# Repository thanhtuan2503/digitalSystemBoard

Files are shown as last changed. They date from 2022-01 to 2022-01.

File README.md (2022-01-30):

# INTRODUCTION TO TICKIT VER1.0 - DIGITAL SYSTEM KIT
Item: Digital System KIT

Date: Jan 10th, 2022

Delivered to: HCMUT CE-LAB

Designed in Vietnam

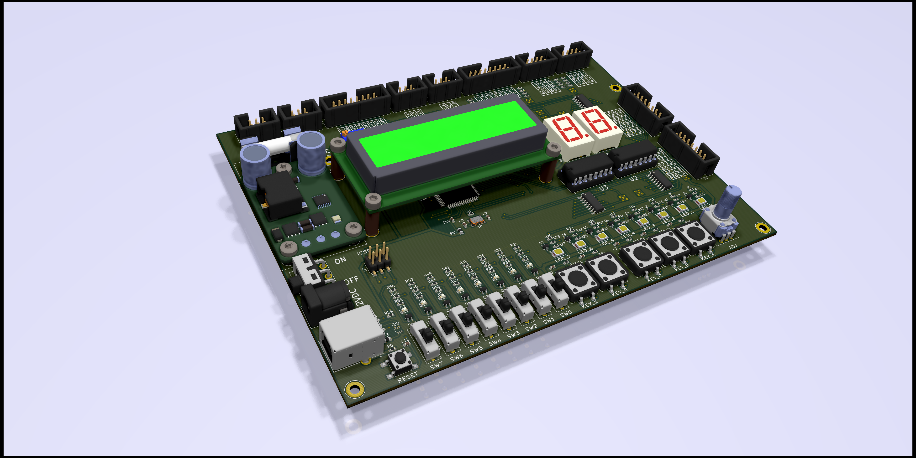
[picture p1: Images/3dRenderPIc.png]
3D Render Board with KiCad

<p align="center">
    3D Render Board with KiCad.
</p>

## TICKIT include all below function block: 
- PWM Generator with  microcontroller ATMEGA64A.
- Display LCD with 16x2 characters.
-  5 Buttons 12x12 mm.
- 8 Switchs 21.1x5.5 mm.
- 8 Display LEDs size 3.5x2.8 mm.
- 2 7- segment LEDs.

Product Introduction in CSE Facebook page :[ KIT thí nghiệm môn học Hệ thống số do thầy và trò Khoa KH&KTMT thiết kế và phát triển](https://www.facebook.com/2180160732207910/posts/3021461968077778/).

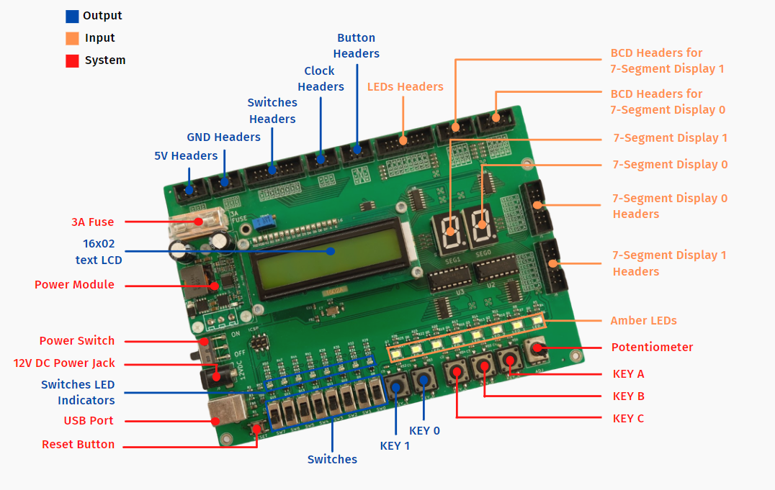
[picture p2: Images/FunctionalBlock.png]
Some functional blocks in TICKIT

<p align="center">
    Some functional blocks in TICKIT.
</p>

##  What's in the Box?
1. TickLab-DSKiT 1.0 Board.

2. TickLab-DSKiT 1.0 Quick Start Guide.

3. Small Screwdriver.

## Documentations and Resources
Available for free access at https://ticklab.vn/dskit

## Getting ready
1. Make sure a 3A fuse tube is properly inserted.

2. Connect the power adapter to the power jack on the board, then turn on the power switch.

3. As soon as the board is powered up, the self-test must be started. The amber LED and 7-segment display will blink at 2Hz during the self-test so you can detect early if any LEDs are dead.

## Fatal Cautions

1. DO NOT connect any outputs to another output. Connecting an output to another one may cause circuit damage, a fire, or an explosion despite a 3A fuse installed.

2. Keep liquid or no-used metal things far away from the board to avoid making a short circuit.

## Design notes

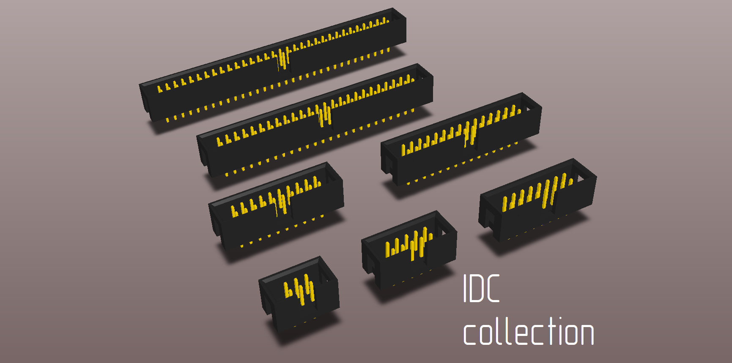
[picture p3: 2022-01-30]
digitalSystemBoard/3dSymbol/IDC_prev.png

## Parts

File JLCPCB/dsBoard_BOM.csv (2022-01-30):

Comment | Designator | Footprint | LCSC
0.1uF | C0,C1,C2,C3,C4,C5,C6,C9,C10,C12,C14 | Capacitor_SMD:C_0603_1608Metric | C14663
22pF | C7,C8,C11,C13 | Capacitor_SMD:C_0603_1608Metric | C1653
LED | D0,D1,D2,D3,D4,D5,D6,D7 | LED_SMD:LED_0603_1608Metric | C72043
WC1602A | DS1 | digitalSystemBoard:WC1602A
3A | F0 | digitalSystemBoard:Fuse
80Ohm | FB1,FB3,FB4,FB5 | digitalSystemBoard:FerriteBead | C141982
MountingHole | H0,H1,H2,H3 | digitalSystemBoard:Mountinghole_M3
Barrel_Jack | J0 | Connector_BarrelJack:BarrelJack_Horizontal
USB-B | J1 | digitalSystemBoard:SAMTEC_USB-B-S-X-X-TH-TR
Conn_02x04_Odd_Even | J2,J3 | Connector_IDC:IDC-Header_2x04_P2.54mm_Vertical
Conn_02x07_Odd_Even | J5,J6 | Connector_IDC:IDC-Header_2x07_P2.54mm_Vertical
Conn_02x08_Odd_Even | J4,J7 | Connector_IDC:IDC-Header_2x08_P2.54mm_Vertical
Conn_02x03_Odd_Even | J8,J9,J10,J11 | Connector_IDC:IDC-Header_2x03_P2.54mm_Vertical
ButtonFirst | KEY0,KEY1,KEY2,KEY3,KEY4 | digitalSystemBoard:Button
LED | LED0,LED1,LED2,LED3,LED4,LED5,LED6,LED7 | digitalSystemBoard:LED_3528 | C210324
Power_Module | PM0 | digitalSystemBoard:Power_Module
BC847 | Q0,Q1,Q2,Q3,Q4,Q5,Q6,Q7,Q8,Q9,Q10,Q11,Q12,Q13,Q14,Q15 | digitalSystemBoard:SO65P210X100-3N | C8659
1M | R1 | Resistor_SMD:R_0603_1608Metric | C22935
22 | R0,R2,R3 | Resistor_SMD:R_0603_1608Metric | C23345
27k | R28,R31,R34,R37,R40,R43,R46,R49 | Resistor_SMD:R_0603_1608Metric | C22967
4.7k | R29,R32,R35,R38,R41,R44,R47,R50 | Resistor_SMD:R_0603_1608Metric | C23162
1.8k | R30,R33,R36,R39,R42,R45,R48,R51 | Resistor_SMD:R_0603_1608Metric | C4177
15k | R4,R7,R10,R13,R16,R19,R22,R25 | Resistor_SMD:R_0603_1608Metric | C22809
10k | R52,R53,R54,R55,R56,R59,R82,R83,R84,R85,R86,R87,R88,R89 | Resistor_SMD:R_0603_1608Metric | C25804
220 | R58 | Resistor_SMD:R_0603_1608Metric | C22962
2.49k | R5,R6,R8,R9,R11,R12,R14,R15,R17,R18,R20,R21,R23,R24,R26,R27 | Resistor_SMD:R_0603_1608Metric | C108190
330 | R60,R61,R62,R63,R64,R65,R66,R67,R68,R69,R70,R71,R72,R73 | Resistor_SMD:R_0603_1608Metric | C23138
47k | R74,R75,R76,R77,R78,R79,R80,R81 | Resistor_SMD:R_0603_1608Metric | C25819
SW_SPDT | SW0 | digitalSystemBoard:SS-12D11
IO_Switch | SW1,SW2,SW3,SW4,SW5,SW6,SW7,SW8 | digitalSystemBoard:SS-12F44G5
ButtonFirst | SW9 | digitalSystemBoard:Button_CLOCK
SMF05C.TCT | TD0 | digitalSystemBoard:SC70-6 | C558425
Potentiometer | TRIM0 | digitalSystemBoard:TRIM_3296W-1-501
KCSA02-105 | U0,U1 | Display_7Segment:7SegmentLED_LTS6760_LTS6780
74HC595 | U9,U11 | Package_SO:SOIC-16_3.9x9.9mm_P1.27mm | C5947
ATmega64A-AU | U12 | Package_QFP:TQFP-64_14x14mm_P0.8mm | C9435
74LS47 | U2,U3 | digitalSystemBoard:DIP_16_PIN_SOCKET
74HC04 | U4 | Package_SO:SOIC-14_3.9x8.7mm_P1.27mm | C5590
Potentiometer | U5 | digitalSystemBoard:RV09S
CH340G | U6 | Package_SO:SOIC-16_3.9x9.9mm_P1.27mm | C14267
ICSP | U7 | Connector_PinHeader_2.54mm:PinHeader_2x03_P2.54mm_Vertical_SMD
74HC165 | U8,U10 | Package_SO:SOIC-16_3.9x9.9mm_P1.27mm | C5613
16MHz | Y0 | Crystal:Crystal_SMD_Abracon_ABM3B-4Pin_5.0x3.2mm | C112586
12MHz | Y1 | Crystal:Crystal_SMD_Abracon_ABM8G-4Pin_3.2x2.5mm | C258939

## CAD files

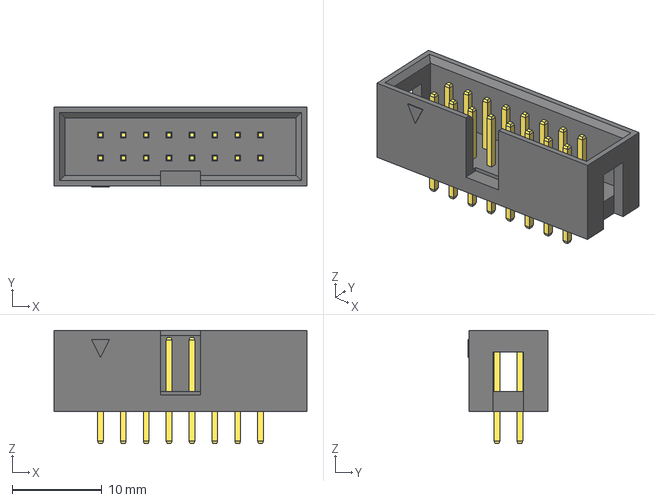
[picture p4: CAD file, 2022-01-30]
digitalSystemBoard/3dSymbol/DS1013 (IDC CONNFLY)/DS1013-16S (IDC-16MS CONNFLY).stp
28.1 x 8.90 x 12.6 mm

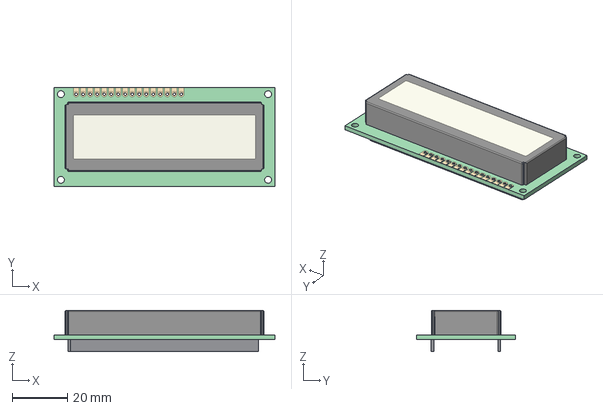
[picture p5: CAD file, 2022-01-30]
digitalSystemBoard/3dSymbol/WC1602A.step
80.0 x 36.0 x 15.0 mm

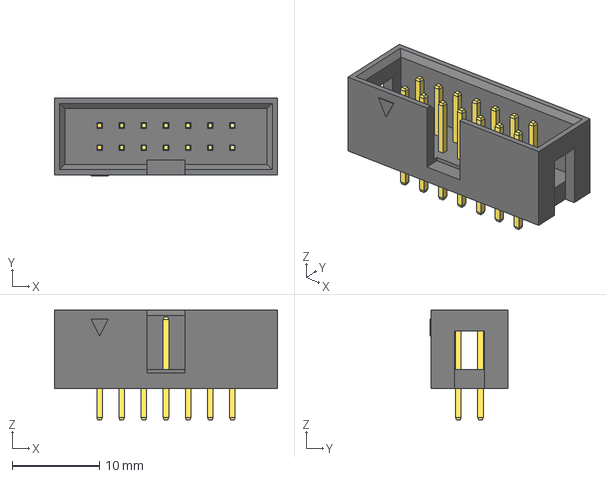
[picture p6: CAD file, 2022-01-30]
digitalSystemBoard/3dSymbol/DS1013 (IDC CONNFLY)/DS1013-14S (IDC-14MS CONNFLY).stp
25.6 x 8.90 x 12.6 mm

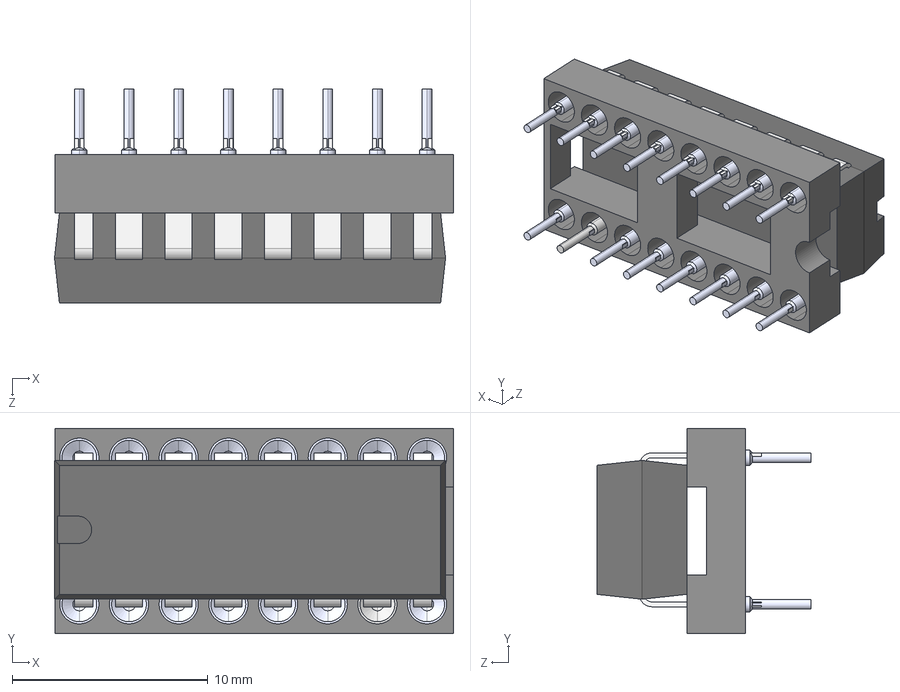
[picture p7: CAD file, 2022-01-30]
digitalSystemBoard/3dSymbol/User-Library-DIP-16-_-socket-214_V3.step
20.4 x 10.5 x 10.9 mm
DIP16 socket62.STEP.STEP
DIP16 socket60.STEP.STEP
DIP16 socket68.STEP.STEP
DIP16 socket53.STEP.STEP
DIP16 socket54.STEP.STEP
DIP16 socket67.STEP.STEP
DIP16 socket57.STEP.STEP
DIP16 socket66.STEP.STEP
DIP16 socket52.STEP.STEP
DIP16 socket59.STEP.STEP
DIP 16 IC4.STEP.STEP
DIP16 socket55.STEP.STEP
DIP16 socket58.STEP.STEP
DIP16 socket63.STEP.STEP
DIP16 socket61.STEP.STEP
DIP16 socket56.STEP.STEP
DIP16 socket65.STEP.STEP
DIP16 socket64.STEP.STEP

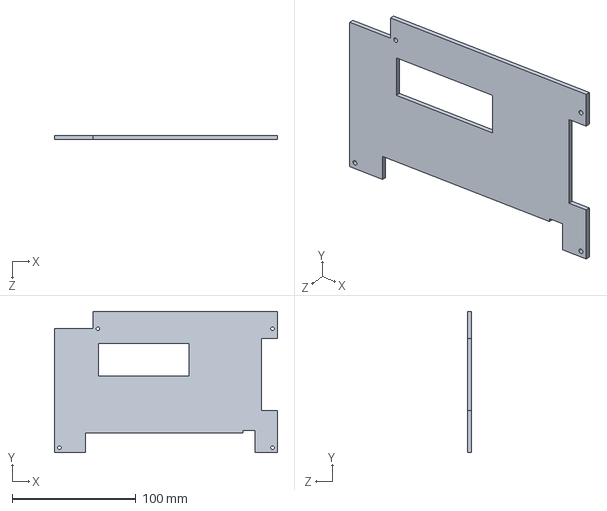
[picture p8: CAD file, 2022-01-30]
PlasticCover/Part1.sldprt
180.0 x 114.0 x 3.00 mm

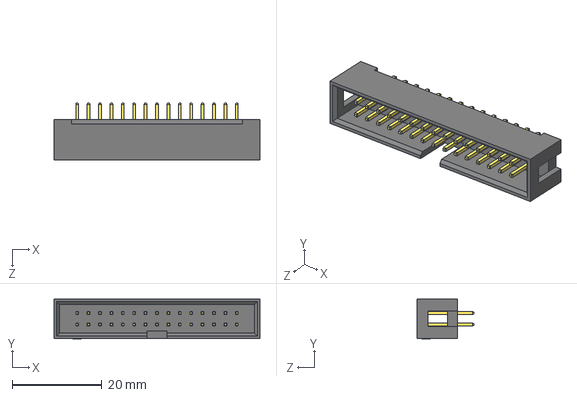
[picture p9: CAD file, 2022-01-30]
digitalSystemBoard/3dSymbol/DS1013 (IDC CONNFLY)/DS1013-30S (IDC-30MS CONNFLY).step
45.9 x 8.90 x 12.6 mm

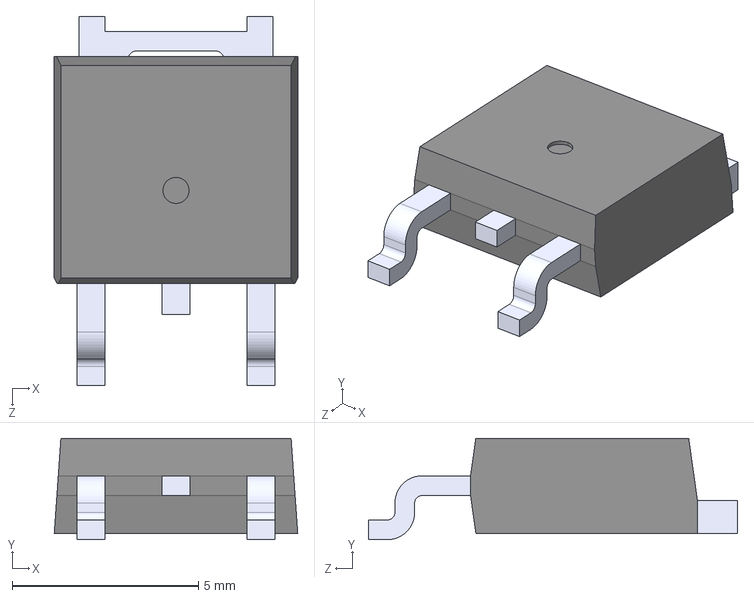
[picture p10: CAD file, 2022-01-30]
digitalSystemBoard/3dSymbol/LM317AMDT.STEP
6.54 x 2.72 x 9.91 mm

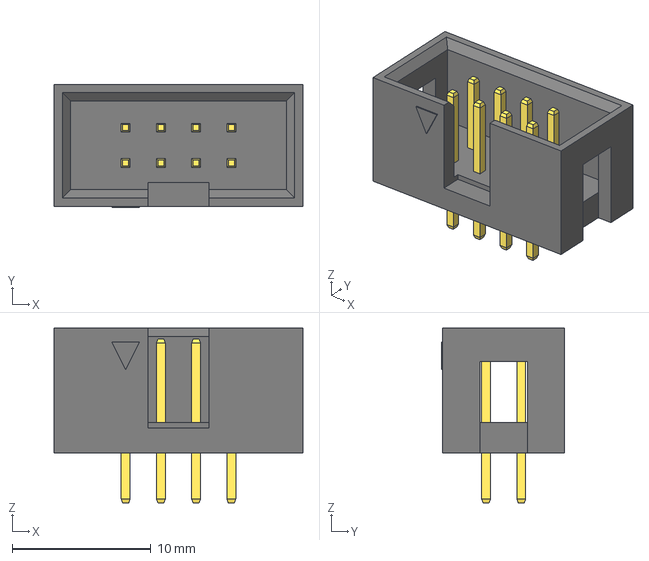
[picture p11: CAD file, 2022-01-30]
digitalSystemBoard/3dSymbol/DS1013 (IDC CONNFLY)/DS1013-8S (IDC-8MS CONNFLY).stp
18.0 x 8.90 x 12.6 mm

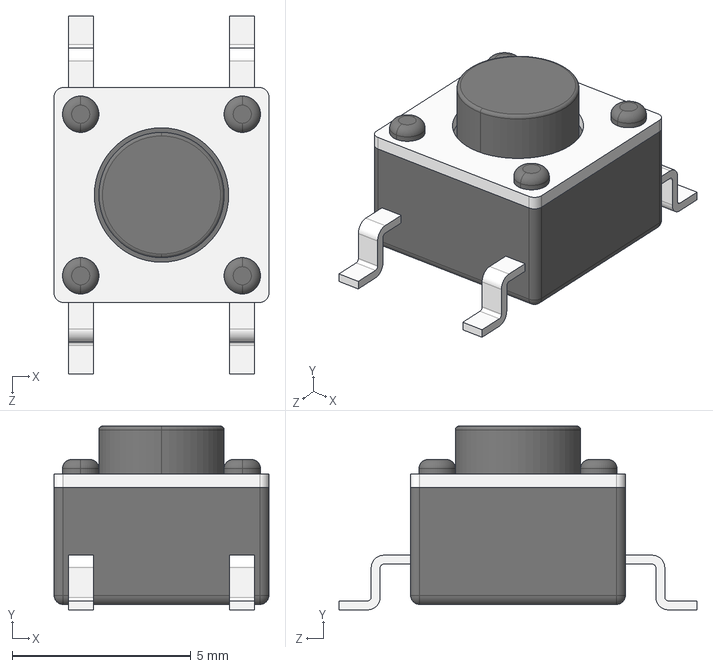
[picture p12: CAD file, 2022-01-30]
digitalSystemBoard/3dSymbol/FSM4JSMA_V2.step
6.00 x 5.13 x 10.0 mm

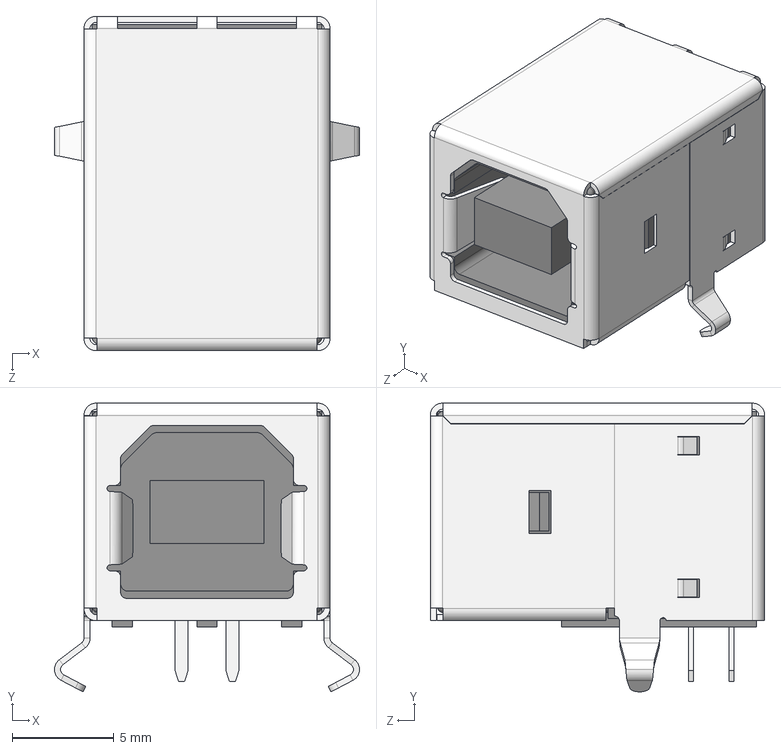
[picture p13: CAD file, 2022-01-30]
digitalSystemBoard/3dSymbol/CUI_DEVICES_UJ2-BH-1-TH.step
15.0 x 14.2 x 16.5 mm

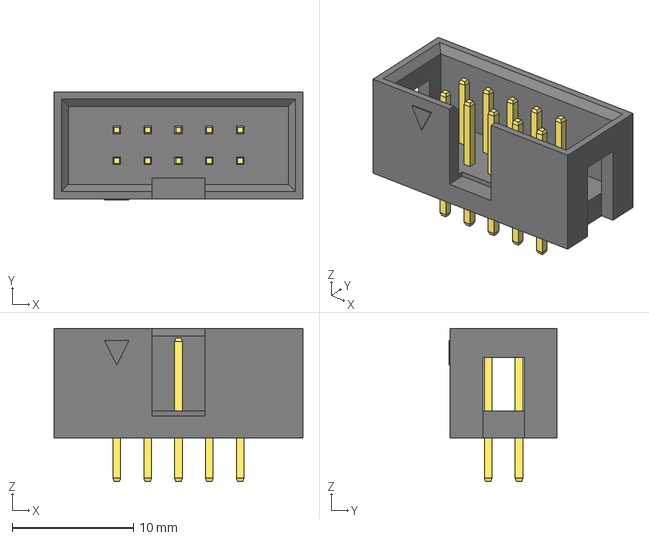
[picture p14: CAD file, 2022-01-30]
digitalSystemBoard/3dSymbol/DS1013 (IDC CONNFLY)/DS1013-10S (IDC-10MS CONNFLY).stp
20.5 x 8.90 x 12.6 mm

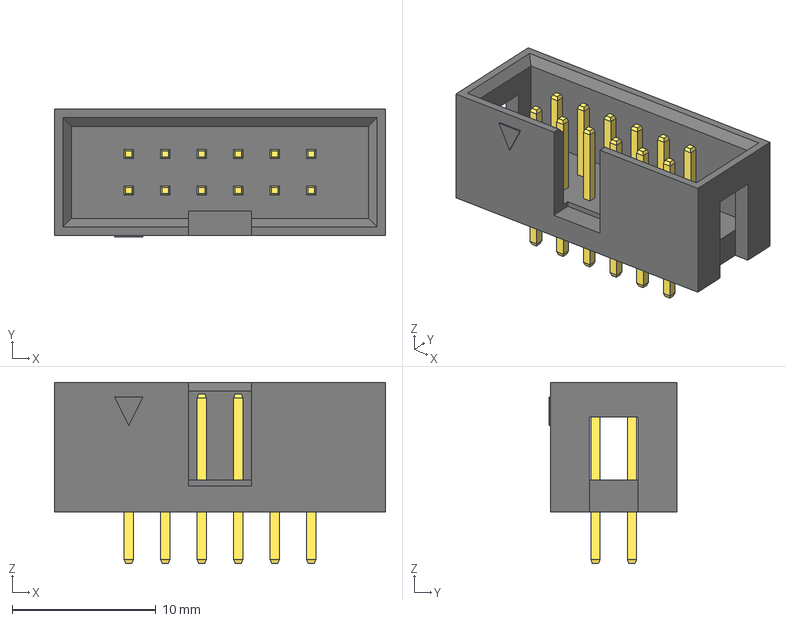
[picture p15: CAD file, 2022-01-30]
digitalSystemBoard/3dSymbol/DS1013 (IDC CONNFLY)/DS1013-12S (IDC-12MS CONNFLY).stp
23.0 x 8.90 x 12.6 mm

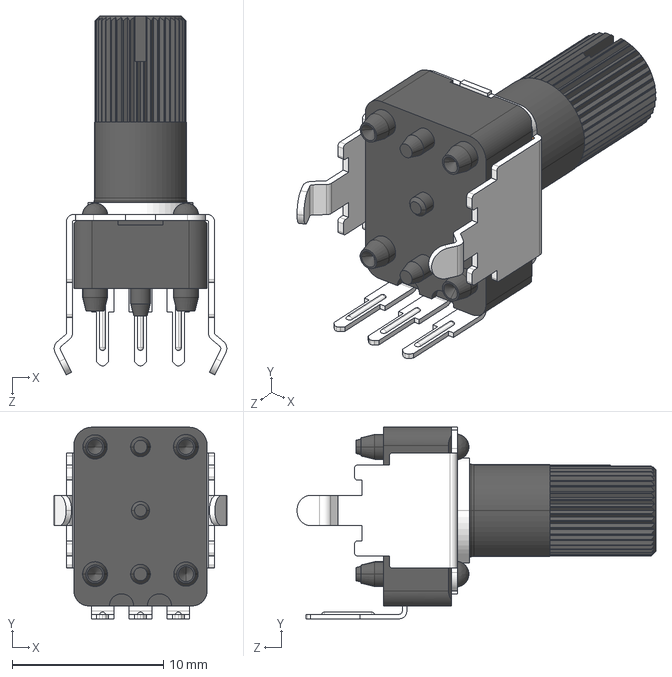
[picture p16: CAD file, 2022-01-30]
digitalSystemBoard/3dSymbol/User-Library-RK09K1130-20-1.step
11.4 x 12.7 x 23.7 mm

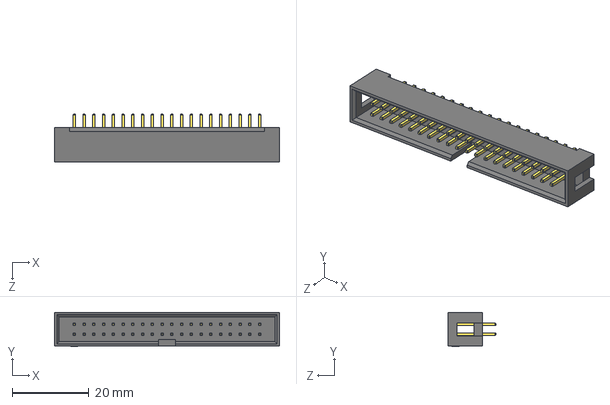
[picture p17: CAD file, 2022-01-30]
digitalSystemBoard/3dSymbol/DS1013 (IDC CONNFLY)/DS1013-40S (IDC-40MS CONNFLY).step
58.6 x 8.90 x 12.6 mm

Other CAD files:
PlasticCover/mica_ver2.0.DWG
digitalSystemBoard/3dSymbol/Fuse.step
digitalSystemBoard/3dSymbol/DS1013 (IDC CONNFLY)/DS1013-50S (IDC-50MS CONNFLY).step
digitalSystemBoard/3dSymbol/Fuse_V2.step
PlasticCover/Part1.SLDDRW
digitalSystemBoard/3dSymbol/2N7002--3DModel-STEP-56544.STEP
digitalSystemBoard/3dSymbol/3296W-1-501.STEP
digitalSystemBoard/3dSymbol/3528 SMD LED.stp
digitalSystemBoard/3dSymbol/BC847BW,115.STEP
digitalSystemBoard/3dSymbol/BC847BW,115Old.STEP
digitalSystemBoard/3dSymbol/DIP_16_PIN_SOCKET.stp
digitalSystemBoard/3dSymbol/DS1013 (IDC CONNFLY)/DS1013-20S (IDC-20MS CONNFLY).stp
digitalSystemBoard/3dSymbol/DS1013 (IDC CONNFLY)/DS1013-26S (IDC-26MS CONNFLY).stp
digitalSystemBoard/3dSymbol/DS1013 (IDC CONNFLY)/DS1013-34S (IDC-34MS CONNFLY).step
digitalSystemBoard/3dSymbol/DS1013 (IDC CONNFLY)/DS1013-60S (IDC-60MS CONNFLY).step
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

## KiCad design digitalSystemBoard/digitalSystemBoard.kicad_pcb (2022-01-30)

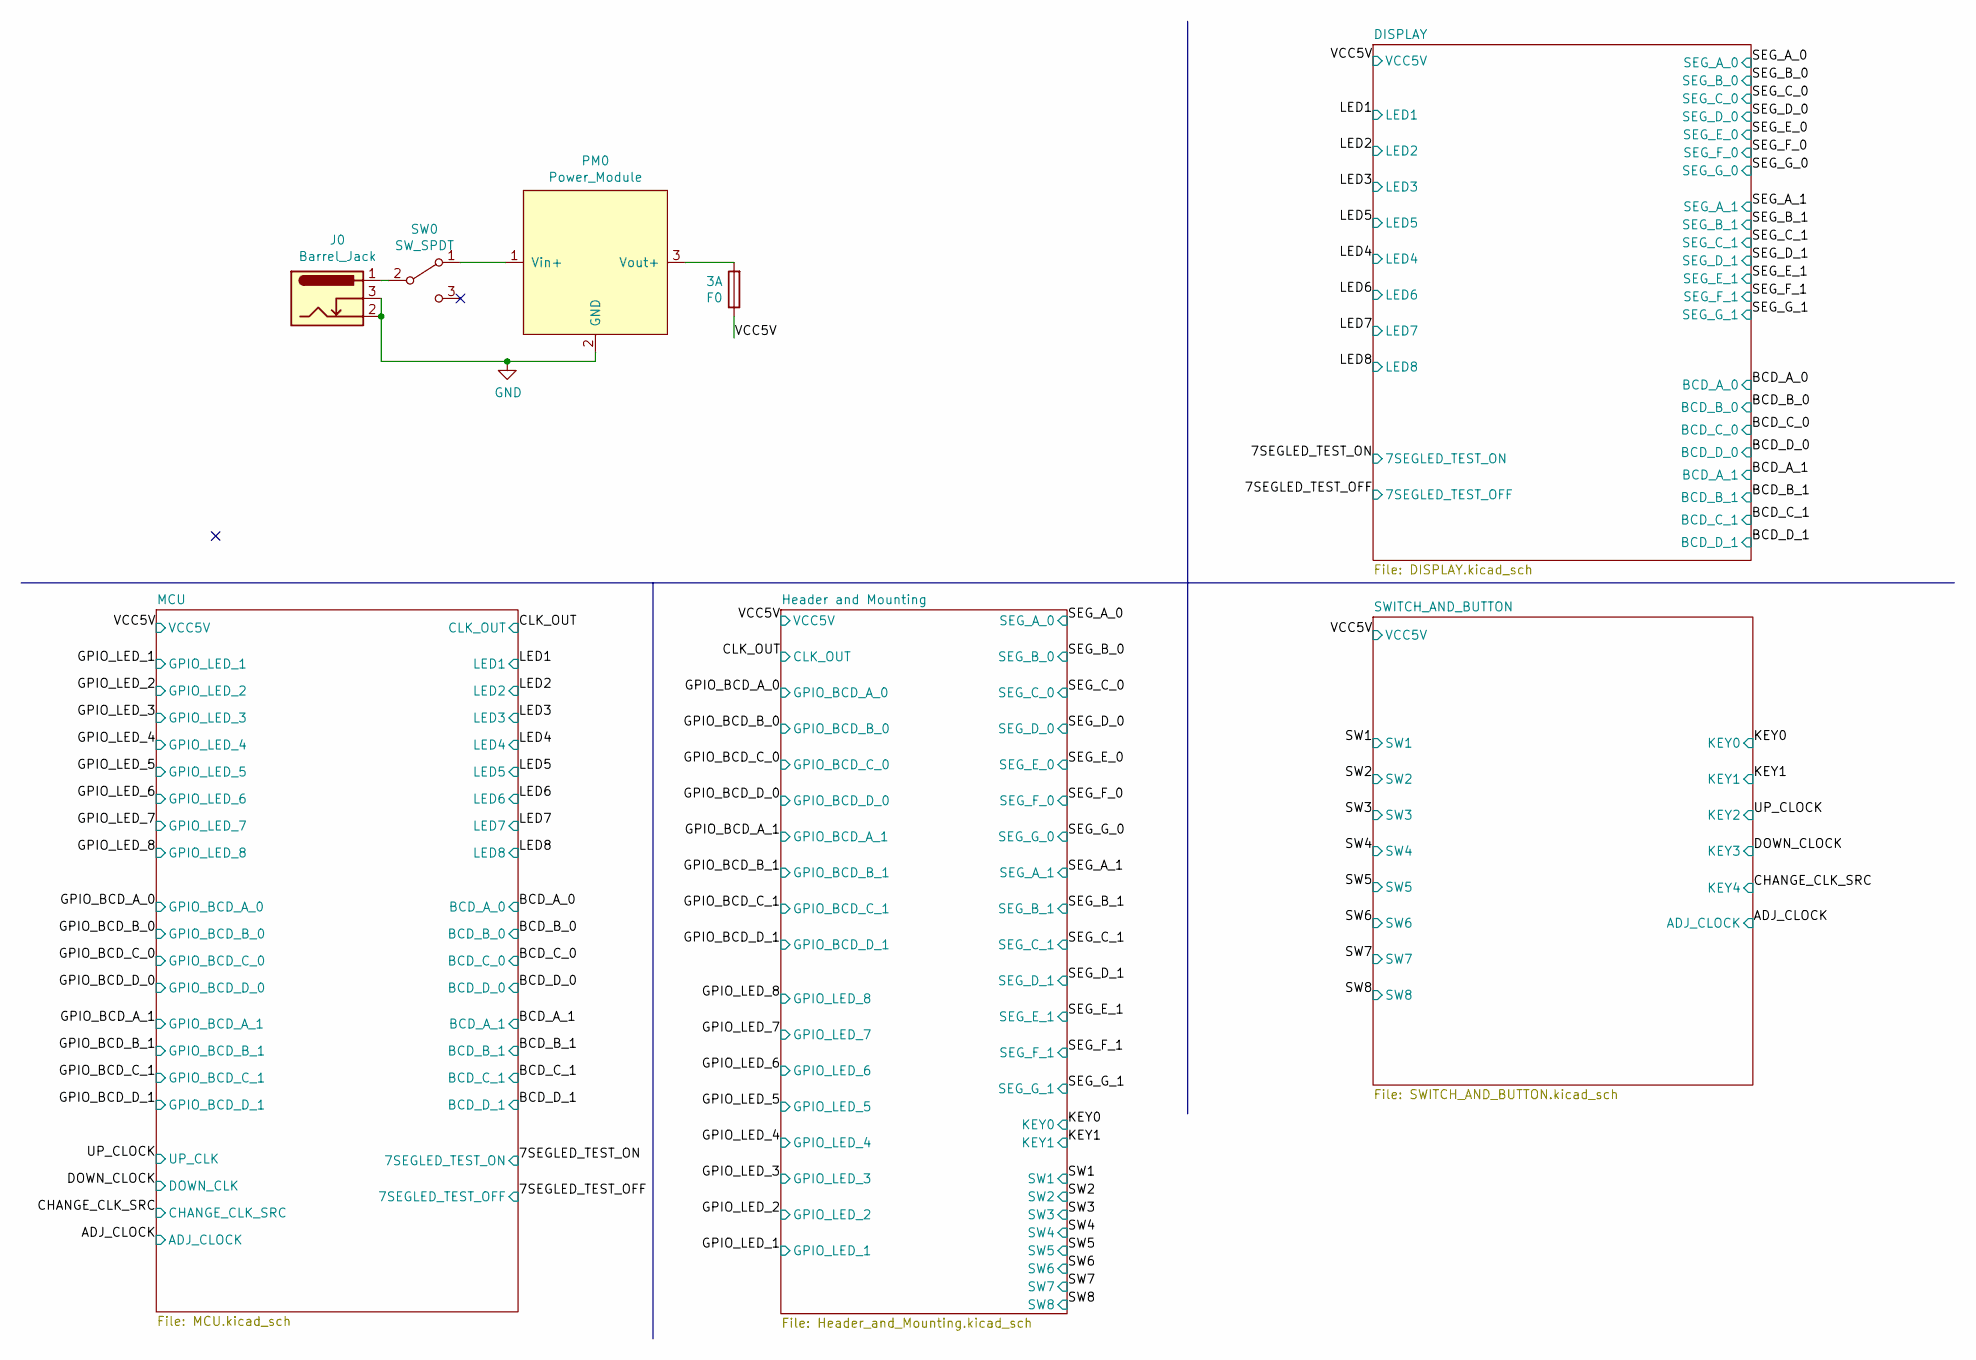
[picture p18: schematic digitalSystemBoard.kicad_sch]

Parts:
F0: 3A; Fuse
J0: Barrel_Jack; BarrelJack_Horizontal
PM0: Power_Module
SW0: SW_SPDT; SS-12D11

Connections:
/VCC5V: F0.1; also elsewhere on the board
GND: J0.2, J0.3, PM0.2 (GND); also elsewhere on the board
unnamed: F0.2, PM0.3 (Vout+)
unnamed: J0.1, SW0.2 (B)
unnamed: PM0.1 (Vin+), SW0.1 (A)

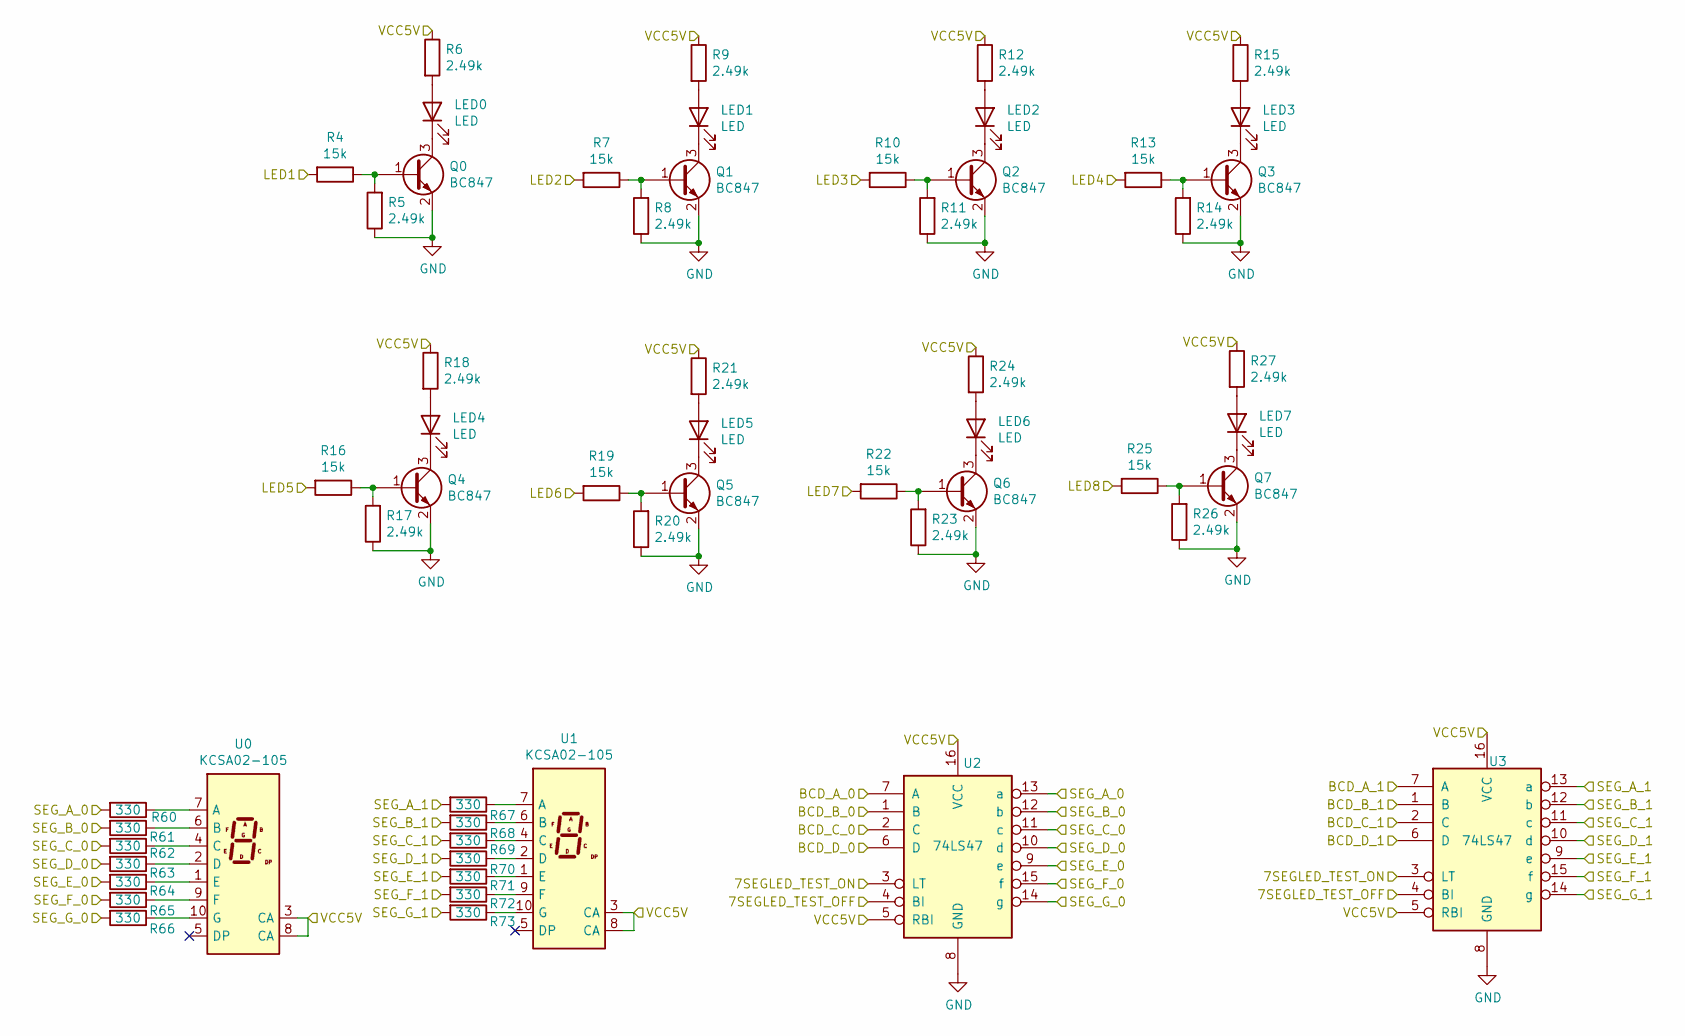
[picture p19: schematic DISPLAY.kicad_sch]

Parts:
LED0, LED1, LED2, LED3, LED4, LED5, LED6, LED7: LED; LED_3528; LCSC C73545
Q0, Q1, Q2, Q3, Q4, Q5, Q6, Q7: BC847; SO65P210X100-3N; LCSC C8659
R4, R7, R10, R13, R16, R19, R22, R25: 15k; R_0603_1608Metric; LCSC C100780
R5, R6, R8, R9, R11, R12, R14, R15, R17, R18, R20, R21, R23, R24, R26, R27: 2.49k; R_0603_1608Metric; LCSC C22908
R60, R61, R62, R63, R64, R65, R66, R67, R68, R69, R70, R71, R72, R73: 330; R_0603_1608Metric; LCSC C23138
U0, U1: KCSA02-105; 7SegmentLED_LTS6760_LTS6780
U2, U3: 74LS47; DIP_16_PIN_SOCKET

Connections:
/7SEGLED_TEST_OFF: U2.4 (BI), U3.4 (BI); also elsewhere on the board
/7SEGLED_TEST_ON: U2.3 (LT), U3.3 (LT); also elsewhere on the board
/BCD_A_0: U2.7 (A); also elsewhere on the board
/BCD_A_1: U3.7 (A); also elsewhere on the board
/BCD_B_0: U2.1 (B); also elsewhere on the board
/BCD_B_1: U3.1 (B); also elsewhere on the board
/BCD_C_0: U2.2 (C); also elsewhere on the board
/BCD_C_1: U3.2 (C); also elsewhere on the board
/BCD_D_0: U2.6 (D); also elsewhere on the board
/BCD_D_1: U3.6 (D); also elsewhere on the board
/LED1: R4.2; also elsewhere on the board
/LED2: R7.2; also elsewhere on the board
/LED3: R10.2; also elsewhere on the board
/LED4: R13.2; also elsewhere on the board
/LED5: R16.2; also elsewhere on the board
/LED6: R19.2; also elsewhere on the board
/LED7: R22.2; also elsewhere on the board
/LED8: R25.2; also elsewhere on the board
/SEG_A_0: R60.2, U2.13 (a); also elsewhere on the board
/SEG_A_1: R67.2, U3.13 (a); also elsewhere on the board
/SEG_B_0: R61.2, U2.12 (b); also elsewhere on the board
/SEG_B_1: R68.2, U3.12 (b); also elsewhere on the board
/SEG_C_0: R62.2, U2.11 (c); also elsewhere on the board
/SEG_C_1: R69.2, U3.11 (c); also elsewhere on the board
/SEG_D_0: R63.2, U2.10 (d); also elsewhere on the board
/SEG_D_1: R70.2, U3.10 (d); also elsewhere on the board
/SEG_E_0: R64.2, U2.9 (e); also elsewhere on the board
/SEG_E_1: R71.2, U3.9 (e); also elsewhere on the board
/SEG_F_0: R65.2, U2.15 (f); also elsewhere on the board
/SEG_F_1: R72.2, U3.15 (f); also elsewhere on the board
/SEG_G_0: R66.2, U2.14 (g); also elsewhere on the board
/SEG_G_1: R73.2, U3.14 (g); also elsewhere on the board
/VCC5V: R6.1, R9.1, R12.1, R15.1, R18.1, R21.1, R24.1, R27.1, U0.3 (CA), U0.8 (CA), U1.3 (CA), U1.8 (CA), U2.5 (RBI), U2.16 (VCC), U3.5 (RBI), U3.16 (VCC); also elsewhere on the board
GND: Q0.2 (E), Q1.2 (E), Q2.2 (E), Q3.2 (E), Q4.2 (E), Q5.2 (E), Q6.2 (E), Q7.2 (E), R5.1, R8.1, R11.1, R14.1, R17.1, R20.1, R23.1, R26.1, U2.8 (GND), U3.8 (GND); also elsewhere on the board
unnamed: LED0.1 (K), Q0.3 (C)
unnamed: LED0.2 (A), R6.2
unnamed: LED1.1 (K), Q1.3 (C)
unnamed: LED1.2 (A), R9.2
unnamed: LED2.1 (K), Q2.3 (C)
unnamed: LED2.2 (A), R12.2
unnamed: LED3.1 (K), Q3.3 (C)
unnamed: LED3.2 (A), R15.2
unnamed: LED4.1 (K), Q4.3 (C)
unnamed: LED4.2 (A), R18.2
unnamed: LED5.1 (K), Q5.3 (C)
unnamed: LED5.2 (A), R21.2
unnamed: LED6.1 (K), Q6.3 (C)
unnamed: LED6.2 (A), R24.2
unnamed: LED7.1 (K), Q7.3 (C)
unnamed: LED7.2 (A), R27.2
unnamed: Q0.1 (B), R4.1, R5.2
unnamed: Q1.1 (B), R7.1, R8.2
unnamed: Q2.1 (B), R10.1, R11.2
unnamed: Q3.1 (B), R13.1, R14.2
unnamed: Q4.1 (B), R16.1, R17.2
unnamed: Q5.1 (B), R19.1, R20.2
unnamed: Q6.1 (B), R22.1, R23.2
unnamed: Q7.1 (B), R25.1, R26.2
unnamed: R60.1, U0.7 (A)
unnamed: R61.1, U0.6 (B)
unnamed: R62.1, U0.4 (C)
unnamed: R63.1, U0.2 (D)
unnamed: R64.1, U0.1 (E)
unnamed: R65.1, U0.9 (F)
unnamed: R66.1, U0.10 (G)
unnamed: R67.1, U1.7 (A)
unnamed: R68.1, U1.6 (B)
unnamed: R69.1, U1.4 (C)
unnamed: R70.1, U1.2 (D)
unnamed: R71.1, U1.1 (E)
unnamed: R72.1, U1.9 (F)
unnamed: R73.1, U1.10 (G)

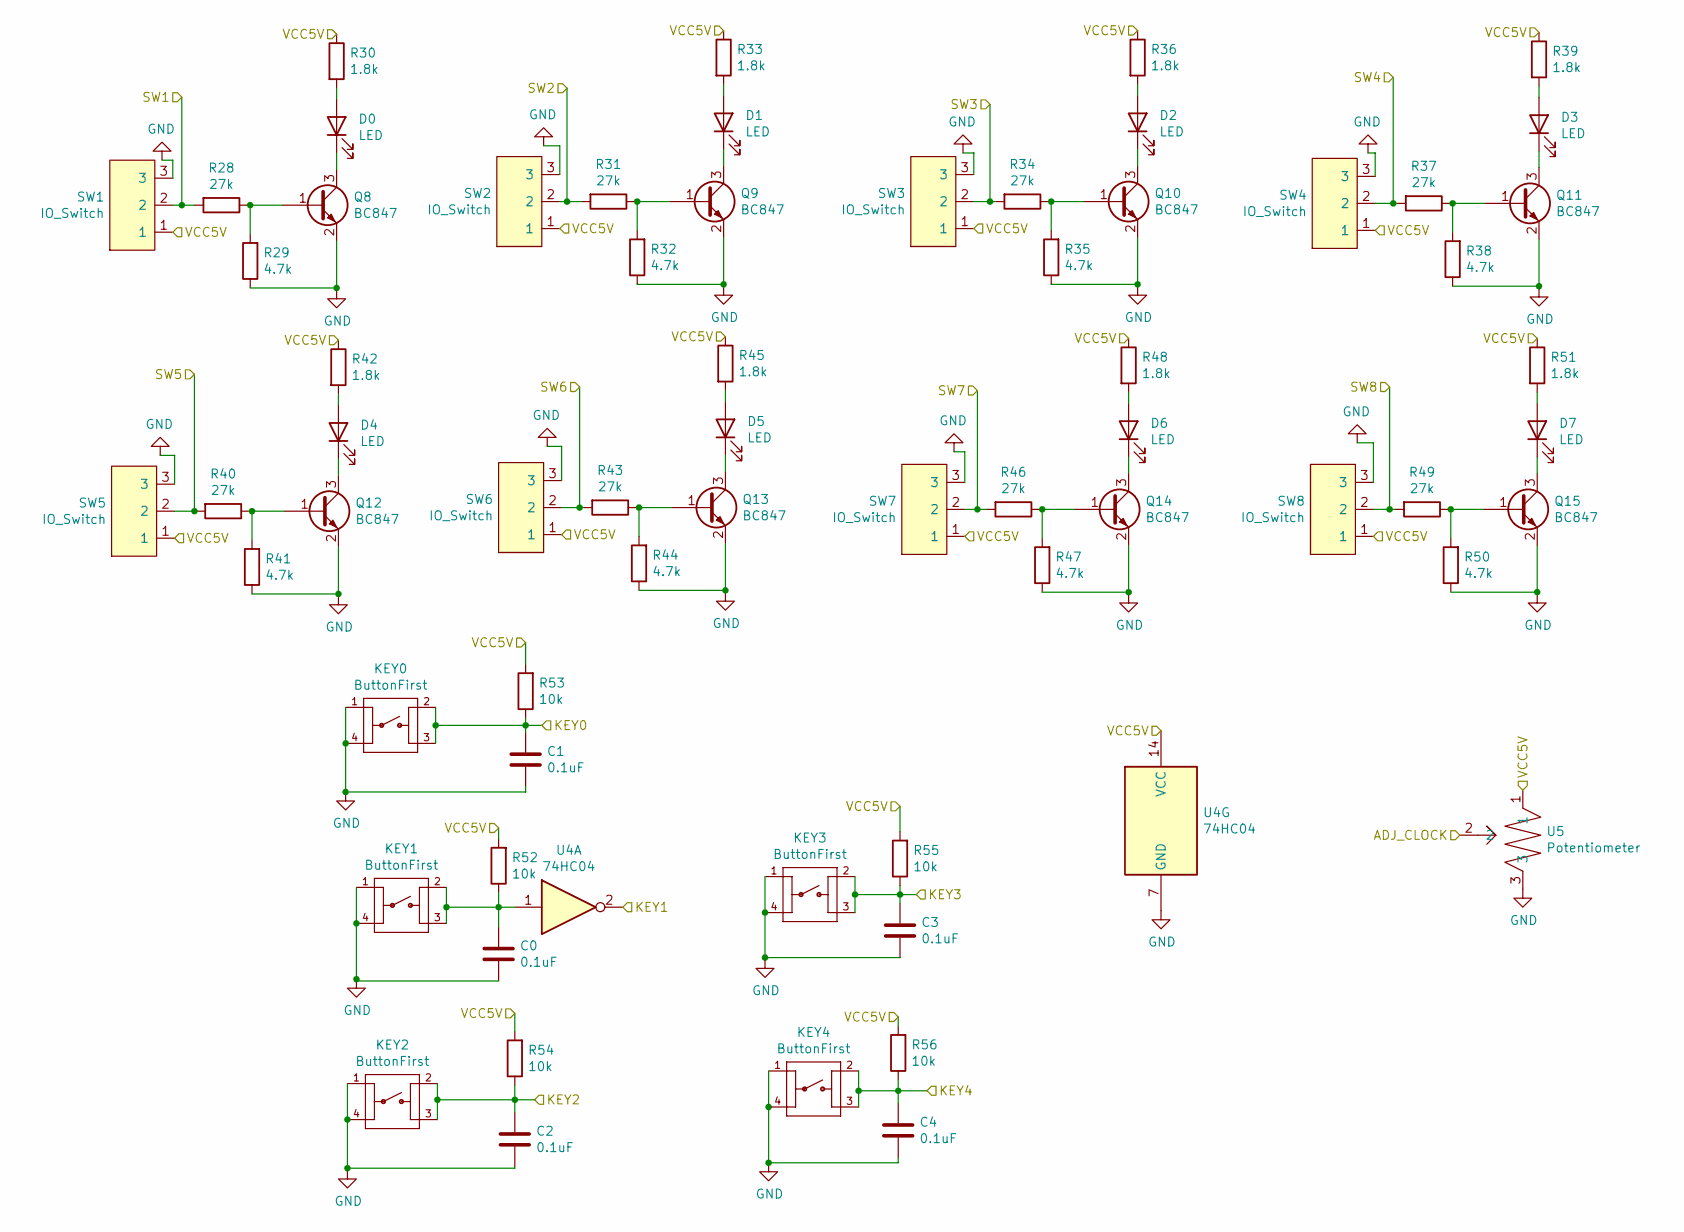
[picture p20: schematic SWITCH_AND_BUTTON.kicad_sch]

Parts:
C0, C1, C2, C3, C4: 0.1uF; C_0603_1608Metric; LCSC C14663
D0, D1, D2, D3, D4, D5, D6, D7: LED; LED_0603_1608Metric; LCSC C72043
KEY0, KEY1, KEY2, KEY3, KEY4: ButtonFirst; Button
Q8, Q9, Q10, Q11, Q12, Q13, Q14, Q15: BC847; SO65P210X100-3N; LCSC C8659
R28, R31, R34, R37, R40, R43, R46, R49: 27k; R_0603_1608Metric; LCSC C25589
R29, R32, R35, R38, R41, R44, R47, R50: 4.7k; R_0603_1608Metric; LCSC C23162
R30, R33, R36, R39, R42, R45, R48, R51: 1.8k; R_0603_1608Metric; LCSC C103360
R52, R53, R54, R55, R56: 10k; R_0603_1608Metric; LCSC C98220
SW1, SW2, SW3, SW4, SW5, SW6, SW7, SW8: IO_Switch; SS-12F44G5
U4: 74HC04; SOIC-14_3.9x8.7mm_P1.27mm; LCSC C5590
U5: Potentiometer; RV09S

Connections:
/ADJ_CLOCK: U5.2; also elsewhere on the board
/CHANGE_CLK_SRC: C4.1, KEY4.2 (e~), KEY4.3, R56.1; also elsewhere on the board
/DOWN_CLOCK: C3.2, KEY3.2 (e~), KEY3.3, R55.1; also elsewhere on the board
/KEY0: C1.1, KEY0.2 (e~), KEY0.3, R53.1; also elsewhere on the board
/KEY1: U4.2; also elsewhere on the board
/SW1: R28.2, SW1.2; also elsewhere on the board
/SW2: R31.2, SW2.2; also elsewhere on the board
/SW3: R34.2, SW3.2; also elsewhere on the board
/SW4: R37.2, SW4.2; also elsewhere on the board
/SW5: R40.2, SW5.2; also elsewhere on the board
/SW6: R43.2, SW6.2; also elsewhere on the board
/SW7: R46.2, SW7.2; also elsewhere on the board
/SW8: R49.2, SW8.2; also elsewhere on the board
/UP_CLOCK: C2.1, KEY2.2 (e~), KEY2.3, R54.1; also elsewhere on the board
/VCC5V: R30.1, R33.1, R36.1, R39.1, R42.1, R45.1, R48.1, R51.1, R52.2, R53.2, R54.2, R55.2, R56.2, SW1.1, SW2.1, SW3.1, SW4.1, SW5.1, SW6.1, SW7.1, SW8.1, U4.14 (VCC), U5.1; also elsewhere on the board
GND: C0.2, C1.2, C2.2, C3.1, C4.2, KEY0.1, KEY0.4, KEY1.1, KEY1.4, KEY2.1, KEY2.4, KEY3.1, KEY3.4, KEY4.1, KEY4.4, Q8.2 (E), Q9.2 (E), Q10.2 (E), Q11.2 (E), Q12.2 (E), Q13.2 (E), Q14.2 (E), Q15.2 (E), R29.1, R32.1, R35.1, R38.1, R41.1, R44.1, R47.1, R50.1, SW1.3, SW2.3, SW3.3, SW4.3, SW5.3, SW6.3, SW7.3, SW8.3, U4.7 (GND), U5.3; also elsewhere on the board
unnamed: C0.1, KEY1.2 (e~), KEY1.3, R52.1, U4.1
unnamed: D0.1 (K), Q8.3 (C)
unnamed: D0.2 (A), R30.2
unnamed: D1.1 (K), Q9.3 (C)
unnamed: D1.2 (A), R33.2
unnamed: D2.1 (K), Q10.3 (C)
unnamed: D2.2 (A), R36.2
unnamed: D3.1 (K), Q11.3 (C)
unnamed: D3.2 (A), R39.2
unnamed: D4.1 (K), Q12.3 (C)
unnamed: D4.2 (A), R42.2
unnamed: D5.1 (K), Q13.3 (C)
unnamed: D5.2 (A), R45.2
unnamed: D6.1 (K), Q14.3 (C)
unnamed: D6.2 (A), R48.2
unnamed: D7.1 (K), Q15.3 (C)
unnamed: D7.2 (A), R51.2
unnamed: Q8.1 (B), R28.1, R29.2
unnamed: Q9.1 (B), R31.1, R32.2
unnamed: Q10.1 (B), R34.1, R35.2
unnamed: Q11.1 (B), R37.1, R38.2
unnamed: Q12.1 (B), R40.1, R41.2
unnamed: Q13.1 (B), R43.1, R44.2
unnamed: Q14.1 (B), R46.1, R47.2
unnamed: Q15.1 (B), R49.1, R50.2

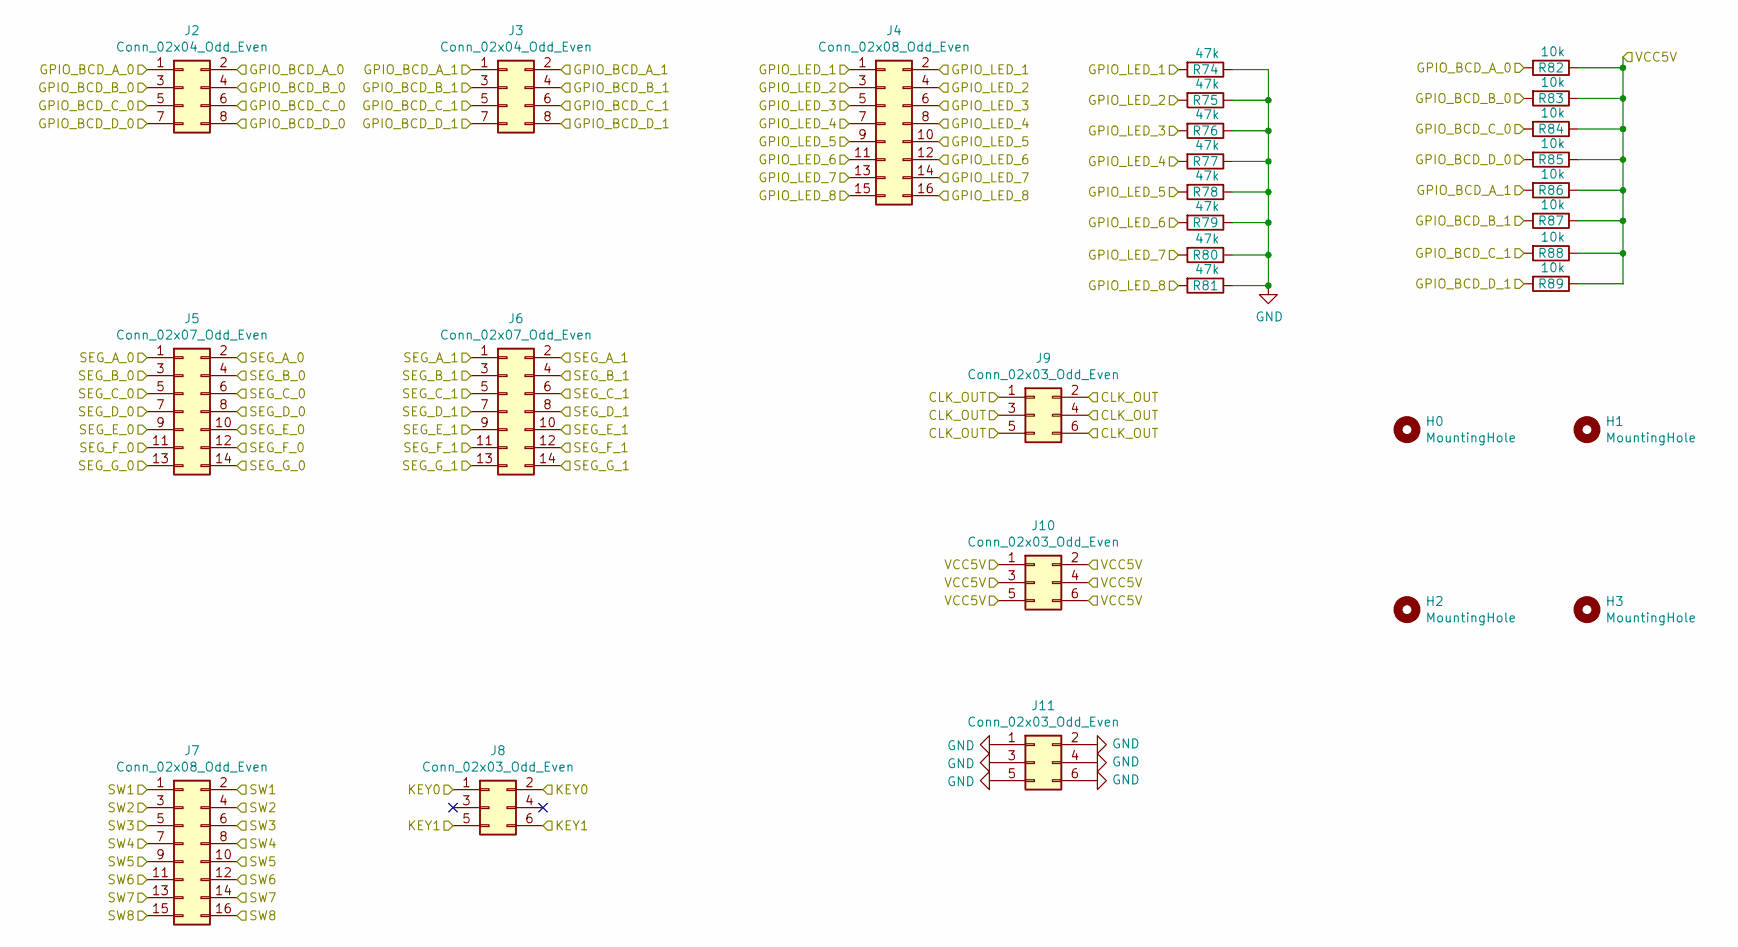
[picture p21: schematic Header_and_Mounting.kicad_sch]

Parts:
H0, H1, H2, H3: MountingHole; Mountinghole_M3
J2, J3: Conn_02x04_Odd_Even; IDC-Header_2x04_P2.54mm_Vertical
J4, J7: Conn_02x08_Odd_Even; IDC-Header_2x08_P2.54mm_Vertical
J5, J6: Conn_02x07_Odd_Even; IDC-Header_2x07_P2.54mm_Vertical
J8, J9, J10, J11: Conn_02x03_Odd_Even; IDC-Header_2x03_P2.54mm_Vertical
R74, R75, R76, R77, R78, R79, R80, R81: 47k; R_0603_1608Metric; LCSC C98220
R82, R83, R84, R85, R86, R87, R88, R89: 10k; R_0603_1608Metric; LCSC C98220

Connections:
/CLK_OUT: J9.1, J9.2, J9.3, J9.4, J9.5, J9.6; also elsewhere on the board
/GPIO_BCD_A_0: J2.1, J2.2, R82.2; also elsewhere on the board
/GPIO_BCD_A_1: J3.1, J3.2, R86.2; also elsewhere on the board
/GPIO_BCD_B_0: J2.3, J2.4, R83.2; also elsewhere on the board
/GPIO_BCD_B_1: J3.3, J3.4, R87.2; also elsewhere on the board
/GPIO_BCD_C_0: J2.5, J2.6, R84.2; also elsewhere on the board
/GPIO_BCD_C_1: J3.5, J3.6, R88.2; also elsewhere on the board
/GPIO_BCD_D_0: J2.7, J2.8, R85.2; also elsewhere on the board
/GPIO_BCD_D_1: J3.7, J3.8, R89.2; also elsewhere on the board
/GPIO_LED_1: J4.1, J4.2, R74.2; also elsewhere on the board
/GPIO_LED_2: J4.3, J4.4, R75.2; also elsewhere on the board
/GPIO_LED_3: J4.5, J4.6, R76.2; also elsewhere on the board
/GPIO_LED_4: J4.7, J4.8, R77.2; also elsewhere on the board
/GPIO_LED_5: J4.9, J4.10, R78.2; also elsewhere on the board
/GPIO_LED_6: J4.11, J4.12, R79.2; also elsewhere on the board
/GPIO_LED_7: J4.13, J4.14, R80.2; also elsewhere on the board
/GPIO_LED_8: J4.15, J4.16, R81.2; also elsewhere on the board
/KEY0: J8.1, J8.2; also elsewhere on the board
/KEY1: J8.5, J8.6; also elsewhere on the board
/SEG_A_0: J5.1, J5.2; also elsewhere on the board
/SEG_A_1: J6.1, J6.2; also elsewhere on the board
/SEG_B_0: J5.3, J5.4; also elsewhere on the board
/SEG_B_1: J6.3, J6.4; also elsewhere on the board
/SEG_C_0: J5.5, J5.6; also elsewhere on the board
/SEG_C_1: J6.5, J6.6; also elsewhere on the board
/SEG_D_0: J5.7, J5.8; also elsewhere on the board
/SEG_D_1: J6.7, J6.8; also elsewhere on the board
/SEG_E_0: J5.9, J5.10; also elsewhere on the board
/SEG_E_1: J6.9, J6.10; also elsewhere on the board
/SEG_F_0: J5.11, J5.12; also elsewhere on the board
/SEG_F_1: J6.11, J6.12; also elsewhere on the board
/SEG_G_0: J5.13, J5.14; also elsewhere on the board
/SEG_G_1: J6.13, J6.14; also elsewhere on the board
/SW1: J7.1, J7.2; also elsewhere on the board
/SW2: J7.3, J7.4; also elsewhere on the board
/SW3: J7.5, J7.6; also elsewhere on the board
/SW4: J7.7, J7.8; also elsewhere on the board
/SW5: J7.9, J7.10; also elsewhere on the board
/SW6: J7.11, J7.12; also elsewhere on the board
/SW7: J7.13, J7.14; also elsewhere on the board
/SW8: J7.15, J7.16; also elsewhere on the board
/VCC5V: J10.1, J10.2, J10.3, J10.4, J10.5, J10.6, R82.1, R83.1, R84.1, R85.1, R86.1, R87.1, R88.1, R89.1; also elsewhere on the board
GND: J11.1, J11.2, J11.3, J11.4, J11.5, J11.6, R74.1, R75.1, R76.1, R77.1, R78.1, R79.1, R80.1, R81.1; also elsewhere on the board

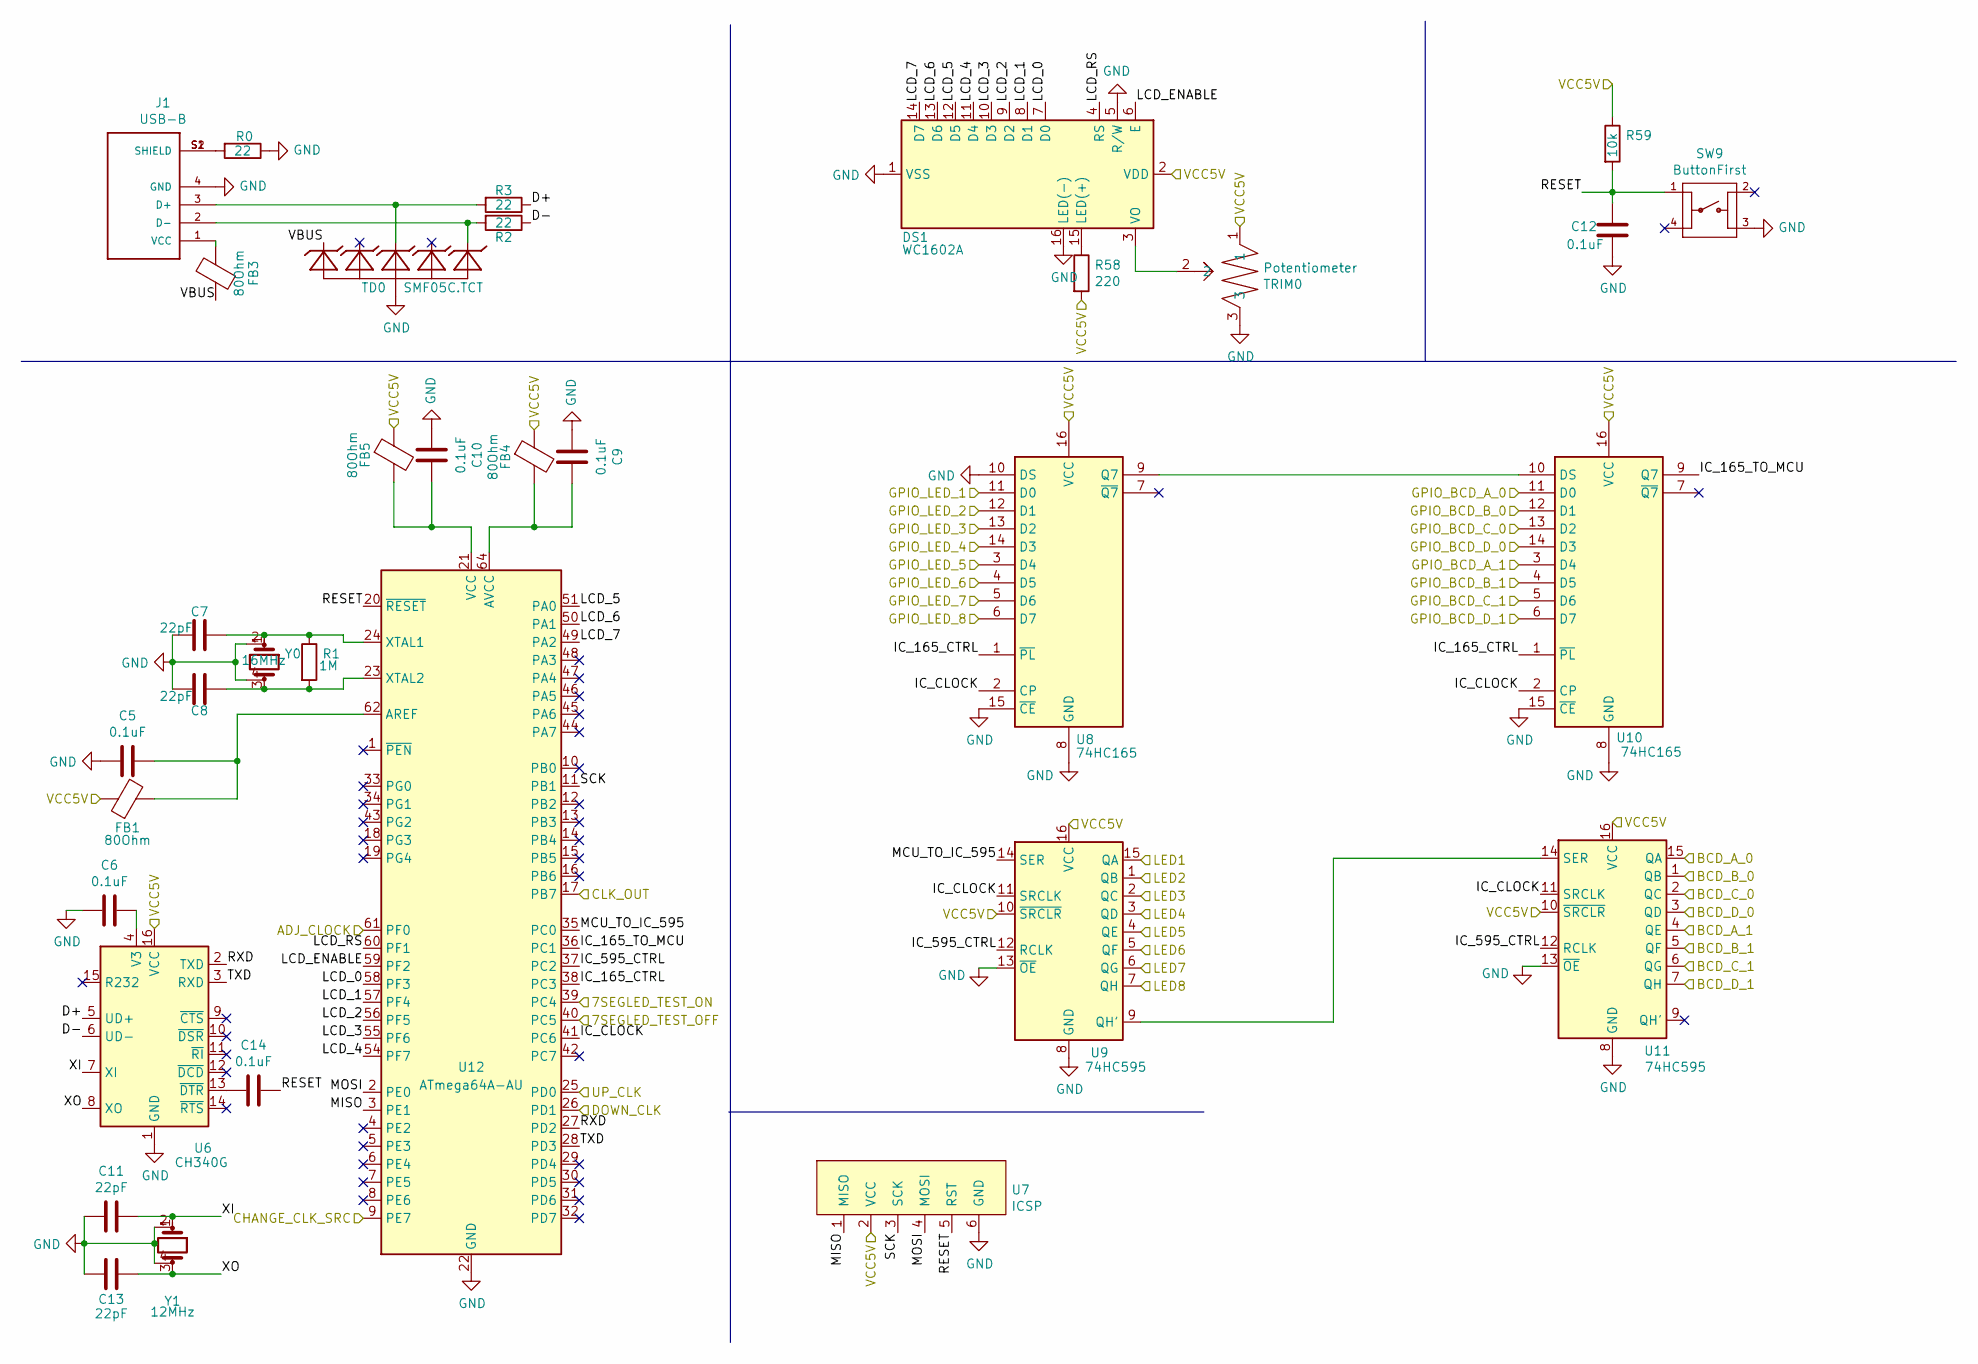
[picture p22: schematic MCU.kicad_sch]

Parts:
C5, C6, C9, C10, C12, C14: 0.1uF; C_0603_1608Metric; LCSC C14663
C7, C8, C11, C13: 22pF; C_0603_1608Metric; LCSC C1653
DS1: WC1602A
FB1, FB3, FB4, FB5: 80Ohm; FerriteBead; LCSC C141982
J1: USB-B; SAMTEC_USB-B-S-X-X-TH-TR
R0, R2, R3: 22; R_0603_1608Metric; LCSC C108405
R1: 1M; R_0603_1608Metric; LCSC C26098
R58: 220; R_0603_1608Metric; LCSC C22962
R59: 10k; R_0603_1608Metric; LCSC C98220
SW9: ButtonFirst; Button_CLOCK
TD0: SMF05C.TCT; SC70-6; LCSC C558425
TRIM0: Potentiometer; TRIM_3296W-1-501
U6: CH340G; SOIC-16_3.9x9.9mm_P1.27mm; LCSC C14267
U7: ICSP; PinHeader_2x03_P2.54mm_Vertical_SMD
U8, U10: 74HC165; SOIC-16_3.9x9.9mm_P1.27mm; LCSC C7742
U9, U11: 74HC595; SOIC-16_3.9x9.9mm_P1.27mm; LCSC C10092
U12: ATmega64A-AU; TQFP-64_14x14mm_P0.8mm; LCSC C9435
Y0: 16MHz; Crystal_SMD_Abracon_ABM3B-4Pin_5.0x3.2mm; LCSC C258963
Y1: 12MHz; Crystal_SMD_Abracon_ABM8G-4Pin_3.2x2.5mm; LCSC C258939

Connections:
/7SEGLED_TEST_OFF: U12.40 (PC5); also elsewhere on the board
/7SEGLED_TEST_ON: U12.39 (PC4); also elsewhere on the board
/ADJ_CLOCK: U12.61 (PF0); also elsewhere on the board
/BCD_A_0: U11.15 (QA); also elsewhere on the board
/BCD_A_1: U11.4 (QE); also elsewhere on the board
/BCD_B_0: U11.1 (QB); also elsewhere on the board
/BCD_B_1: U11.5 (QF); also elsewhere on the board
/BCD_C_0: U11.2 (QC); also elsewhere on the board
/BCD_C_1: U11.6 (QG); also elsewhere on the board
/BCD_D_0: U11.3 (QD); also elsewhere on the board
/BCD_D_1: U11.7 (QH); also elsewhere on the board
/CHANGE_CLK_SRC: U12.9 (PE7); also elsewhere on the board
/CLK_OUT: U12.17 (PB7); also elsewhere on the board
/DOWN_CLOCK: U12.26 (PD1); also elsewhere on the board
/GPIO_BCD_A_0: U10.11 (D0); also elsewhere on the board
/GPIO_BCD_A_1: U10.3 (D4); also elsewhere on the board
/GPIO_BCD_B_0: U10.12 (D1); also elsewhere on the board
/GPIO_BCD_B_1: U10.4 (D5); also elsewhere on the board
/GPIO_BCD_C_0: U10.13 (D2); also elsewhere on the board
/GPIO_BCD_C_1: U10.5 (D6); also elsewhere on the board
/GPIO_BCD_D_0: U10.14 (D3); also elsewhere on the board
/GPIO_BCD_D_1: U10.6 (D7); also elsewhere on the board
/GPIO_LED_1: U8.11 (D0); also elsewhere on the board
/GPIO_LED_2: U8.12 (D1); also elsewhere on the board
/GPIO_LED_3: U8.13 (D2); also elsewhere on the board
/GPIO_LED_4: U8.14 (D3); also elsewhere on the board
/GPIO_LED_5: U8.3 (D4); also elsewhere on the board
/GPIO_LED_6: U8.4 (D5); also elsewhere on the board
/GPIO_LED_7: U8.5 (D6); also elsewhere on the board
/GPIO_LED_8: U8.6 (D7); also elsewhere on the board
/LED1: U9.15 (QA); also elsewhere on the board
/LED2: U9.1 (QB); also elsewhere on the board
/LED3: U9.2 (QC); also elsewhere on the board
/LED4: U9.3 (QD); also elsewhere on the board
/LED5: U9.4 (QE); also elsewhere on the board
/LED6: U9.5 (QF); also elsewhere on the board
/LED7: U9.6 (QG); also elsewhere on the board
/LED8: U9.7 (QH); also elsewhere on the board
/MCU/D+: R3.1, U6.5 (UD+)
/MCU/D-: R2.1, U6.6 (UD-)
/MCU/IC_165_CTRL: U8.1 (~PL), U10.1 (~PL), U12.38 (PC3)
/MCU/IC_165_TO_MCU: U10.9 (Q7), U12.36 (PC1)
/MCU/IC_595_CTRL: U9.12 (RCLK), U11.12 (RCLK), U12.37 (PC2)
/MCU/IC_CLOCK: U8.2 (CP), U9.11 (SRCLK), U10.2 (CP), U11.11 (SRCLK), U12.41 (PC6)
/MCU/LCD_0: DS1.7 (D0), U12.58 (PF3)
/MCU/LCD_1: DS1.8 (D1), U12.57 (PF4)
/MCU/LCD_2: DS1.9 (D2), U12.56 (PF5)
/MCU/LCD_3: DS1.10 (D3), U12.55 (PF6)
/MCU/LCD_4: DS1.11 (D4), U12.54 (PF7)
/MCU/LCD_5: DS1.12 (D5), U12.51 (PA0)
/MCU/LCD_6: DS1.13 (D6), U12.50 (PA1)
/MCU/LCD_7: DS1.14 (D7), U12.49 (PA2)
/MCU/LCD_ENABLE: DS1.6 (E), U12.59 (PF2)
/MCU/LCD_RS: DS1.4 (RS), U12.60 (PF1)
/MCU/MCU_TO_IC_595: U9.14 (SER), U12.35 (PC0)
/MCU/MISO: U7.1 (MISO), U12.3 (PE1)
/MCU/MOSI: U7.4 (MOSI), U12.2 (PE0)
/MCU/RESET: C12.1, C14.1, R59.2, SW9.1, U7.5 (RST), U12.20 (~RESET)
/MCU/RXD: U6.2 (TXD), U12.27 (PD2)
/MCU/SCK: U7.3 (SCK), U12.11 (PB1)
/MCU/TXD: U6.3 (RXD), U12.28 (PD3)
/MCU/VBUS: FB3.1, TD0.1 (IO1)
/MCU/XI: C11.1, U6.7 (XI), Y1.1
/MCU/XO: C13.1, U6.8 (XO), Y1.3
/UP_CLOCK: U12.25 (PD0); also elsewhere on the board
/VCC5V: DS1.2 (VDD), FB1.1, FB4.1, FB5.1, R58.2, R59.1, TRIM0.1, U6.16 (VCC), U7.2 (VCC), U8.16 (VCC), U9.10 (~SRCLR), U9.16 (VCC), U10.16 (VCC), U11.10 (~SRCLR), U11.16 (VCC); also elsewhere on the board
GND: C5.2, C6.2, C7.2, C8.2, C9.2, C10.2, C11.2, C12.2, C13.2, DS1.1 (VSS), DS1.5 (R/W), DS1.16 (LED(-)), J1.4 (GND), R0.1, SW9.3, TD0.2 (GND), TRIM0.3, U6.1 (GND), U7.6 (GND), U8.8 (GND), U8.10 (DS), U8.15 (~CE), U9.8 (GND), U9.13 (~OE), U10.8 (GND), U10.15 (~CE), U11.8 (GND), U11.13 (~OE), U12.22 (GND), U12.53 (GND), U12.63 (GND), Y0.2 (GND), Y0.4 (GND), Y1.2 (GND), Y1.4 (GND); also elsewhere on the board
unnamed: C5.1, FB1.2, U12.62 (AREF)
unnamed: C6.1, U6.4 (V3)
unnamed: C7.1, R1.1, U12.24 (XTAL1), Y0.1
unnamed: C8.1, R1.2, U12.23 (XTAL2), Y0.3
unnamed: C9.1, FB4.2, U12.64 (AVCC)
unnamed: C10.1, FB5.2, U12.21 (VCC), U12.52 (VCC)
unnamed: C14.2, U6.13 (~DTR)
unnamed: DS1.3 (VO), TRIM0.2
unnamed: DS1.15 (LED(+)), R58.1
unnamed: FB3.2, J1.1 (VCC)
unnamed: J1.2 (D-), R2.2, TD0.6 (IO5)
unnamed: J1.3 (D+), R3.2, TD0.4 (IO3)
unnamed: J1.S1 (SHIELD), J1.S2 (SHIELD), R0.2
unnamed: U8.9 (Q7), U10.10 (DS)
unnamed: U9.9 (QH'), U11.14 (SER)

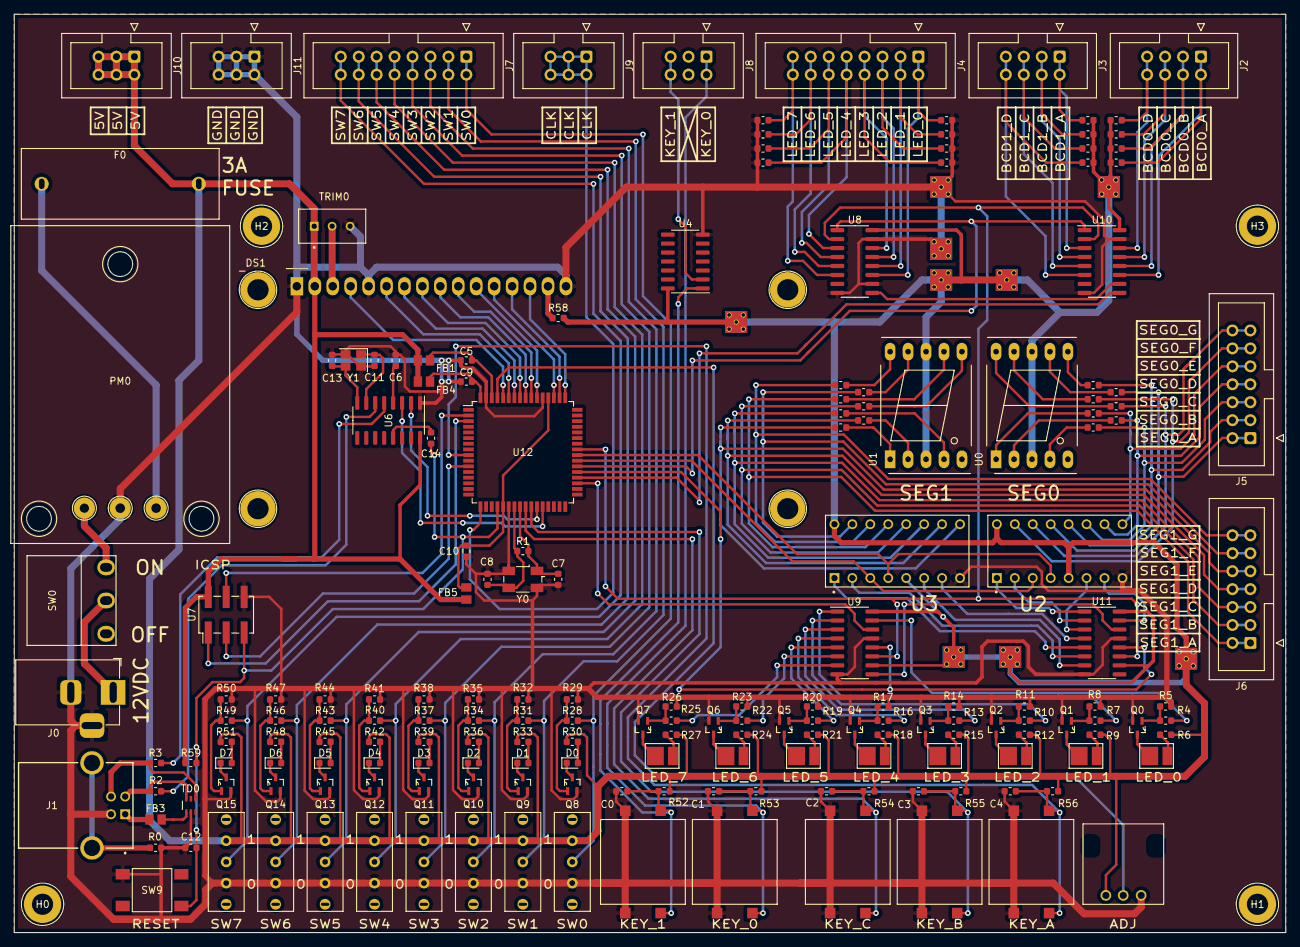
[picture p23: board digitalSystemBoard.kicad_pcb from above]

Board: 2 copper layers, 180.0 x 130.0 mm, 191 parts (0 on the bottom side), 172 nets.

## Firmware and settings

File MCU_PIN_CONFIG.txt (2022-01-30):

OUTPUT_CLOCK :		OC1A_PB5

INPUT_POTETIONMETER:	ADC7_PF7
KEY2_UP:		INT0_PD0	
KEY3_DOWN		INT1_PD1
KEY4_CHANGE_CLK_SRC	INT2_PD2

IC_CLOCK:		OC0A_PB7
MCU_TO_IC_164:		PCINT0_PB0
IC_165_TO_MCU:		INT3_PD3
IC_164_CTRL:		PD4
IC_165_CTRL:		PD7
7SEGLED_TEST_ON		PB6	(WRITE LOGIC 0 TO THIS PIN AND LOGIC 1 TO 7SEGLED_TEST_ON TO ACTIVE)
7SEGLED_TEST_OFF	PC7	(WRITE LOGIC 0 TO ACTIVE)

LCD_0:			PF0
LCD_1:			PF1
LCD_2:			PF2
LCD_3:			PF3
LCD_4:			PF4
LCD_5:			PD5
LCD_6:			PD6
LCD_7:			PB4
LCD_RS:			PE6
LCD_ENABLE:		PC6

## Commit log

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2020-10-14 Upload Schematic of Board
    [OOI.sch, OUT_PIN.sch]
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2020-10-15 Update footprints and CLOCK_BLOCK Sch
    [OOI.sch, digitalSystemBoard.sch]
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2020-10-18 Redesign CLOCK_GENERATOR and add footprints for LM317, 5W resistor
    [CLOCK_GENERATOR.sch, OOI.sch, OUT_PIN.sch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]
2020-10-19 Update a part of footprint
    [CLOCK_GENERATOR.sch, CUI_DEVICES_UJ2-BH-1-TH.step, OOI.sch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]
2020-10-19 Upload schematic full agan
    [CLOCK_GENERATOR.sch, Power Barrel Connector Jack 694106301002.stp, RK09K1130AH1.STEP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]
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2020-10-20 Fixed Error
    [BC847BW,115.STEP, EG1249.step, ST-LM317T.stp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]
2020-10-20 Upload after error
    [digitalSystemBoard.kicad_pcb, digitalSystemBoard.sch, noname.kicad_pcb]
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2020-10-20 Start to place component
    [OS102011MS2QN1--3DModel-STEP-1.STEP, digitalSystemBoard.kicad_pcb, digitalSystemBoard.xlsx]
2020-10-21 Add usb source block
    [CLOCK_GENERATOR.sch, LMV358IDGKR--3DModel-STEP-56544.STEP, LP2985-33DBVRG4.STEP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]
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2020-10-21 Add all footprints of usb source block
    [digitalSystemBoard.kicad_pcb]
2020-10-21 Add fb and smfc frpt
    [FBMH2012HM800-T.STEP, SMF05C.STEP]
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2020-10-21 Ready for commit after update
    [digitalSystemBoard.kicad_pcb]
2020-10-23 Update I/O and MCU schematic
    [CLOCK_GENERATOR.sch, OUT_PIN.sch, digitalSystemBoard.kicad_pcb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]
2020-10-24 Update I/O schematic, Complete layout, Start routing
    [CLOCK_GENERATOR.sch, R-PDSO-G4.STEP, digitalSystemBoard.kicad_pcb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]
2020-10-26 Hot fix schematics. Update MCU layout
    [CLOCK_GENERATOR.sch, digitalSystemBoard.kicad_pcb]
2020-10-29 Update new layout, add power vias
    [CLOCK_GENERATOR.sch, LM358M.STEP, LMV358AIDGKR.STEP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]
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2020-11-10 Hot fix Libs. Update schematic
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2020-11-25 Change grid size to 10mils and wire components in power supply and display sheet
    [DISPLAY.sch, Header.sch, SWITCH_AND_BUTTON.sch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]
2020-12-02 Change grid size of all schematic
    [DISPLAY.sch, MCU.sch, SWITCH_AND_BUTTON.sch]
2020-12-03 Update Schematic for review
    [DISPLAY.sch, Header.sch, LM317AMDT.STEP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]
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2020-12-03 Review schematic and change pin in slide switch
    [SWITCH_AND_BUTTON.sch]
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2020-12-05 Add full footprint. Draw layout board
    [DIP_16_PIN_SOCKET.stp, DISPLAY.sch, DS1013-10S (IDC-10MS CONNFLY).stp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]
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2020-12-08 Layout 70 percent board
    [Header_and_Mounting.sch, MCU.sch, digitalSystemBoard.kicad_pcb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]
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2020-12-08 Add net for ICSP and USB
    [digitalSystemBoard.kicad_pcb]
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2020-12-09 Ready for power line wiring
    [digitalSystemBoard.kicad_pcb]
2020-12-09 power line start wiring
    [digitalSystemBoard.kicad_pcb]
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2020-12-10 Hot fix: added resistors for ic 7447
    [DISPLAY.sch, digitalSystemBoard.kicad_pcb]
2020-12-10 Hot fix: modifiy LCD footprint
    [MCU.sch, digitalSystemBoard.kicad_pcb]
2020-12-10 Hot fix: move fuse
    [digitalSystemBoard.kicad_pcb]
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2020-12-12 export Gerber files for production
    [digitalSystemBoard-B_Cu.gbr, digitalSystemBoard-B_Mask.gbr, digitalSystemBoard-B_Paste.gbr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]
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2020-12-12 Hot fix: change symbol and footprint of the barrell jack
    [DISPLAY.sch, Header_and_Mounting.sch, MCU.sch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]
2020-12-12 re-route power line, reset origin
    [digitalSystemBoard.kicad_pcb]
2020-12-12 re-route power line and re-pour poly and reset origin
    [digitalSystemBoard.kicad_pcb]
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2020-12-25 Hot fix: Change footprint. Fix power schematic.
    [DISPLAY.sch, Header_and_Mounting.sch, SWITCH_AND_BUTTON.sch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]
2020-12-28 Debug error of schematic.
2020-12-31 Debug error part 2
    [digitalSystemBoard.sch]
2021-01-04 Final debug footprints error
2021-01-04 Hot fix: edited power switch and button footprint
    [digitalSystemBoard.kicad_pcb]
2021-01-04 Add fill zone layer
    [digitalSystemBoard.kicad_pcb]
2021-01-14 Hot fix: Modify Reset button footprint
    [MCU.sch, digitalSystemBoard.kicad_pcb]
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2021-01-26 Edit BJT BC847 References
    [digitalSystemBoard.kicad_pcb]
2021-01-26 Modify Power switch and Fuse footprints
    [digitalSystemBoard.kicad_pcb]
2021-01-27 Add discharge resistor for power block
    [digitalSystemBoard.kicad_pcb, digitalSystemBoard.sch]
2021-01-27 Pour front copper layer
    [digitalSystemBoard.kicad_pcb]
2021-01-27 Modify LED 3528 footprint.
    [digitalSystemBoard.kicad_pcb]
2021-01-31 Add keepout areas for Power Block. Modify 7-segment LED schematic
    [DISPLAY.sch, digitalSystemBoard.kicad_pcb]
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2021-03-03 Fix bug in BCD, add an rheostat on Vo and add an resistor on LED+
    [Header_and_Mounting.sch, MCU.sch, digitalSystemBoard.kicad_pcb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]
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2021-03-16 Replace R array by 16 single R
    [DISPLAY.sch, Header_and_Mounting.sch, SWITCH_AND_BUTTON.sch]
2021-04-01 Add IC 74HC595 and R for input pin
    [Header_and_Mounting.sch, MCU.sch, digitalSystemBoard.kicad_pcb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]
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2021-05-07 Add Power_module to schematic and pcb
    [digitalSystemBoard.kicad_pcb, digitalSystemBoard.sch]
2021-05-08 Fix name of all device
    [DISPLAY.sch, Header_and_Mounting.sch, MCU.sch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]
2021-05-08 Update voltage bias for LED green and LED yellow
    [DISPLAY.sch, SWITCH_AND_BUTTON.sch]
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2021-05-09 Change drill hole size for Power_Module
    [MCU.sch, digitalSystemBoard.kicad_pcb]
2021-05-10 Add BOM file and CPL file
    [DISPLAY.sch, Header_and_Mounting.sch, MCU.sch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]
2021-05-10 Ready for generate Bom file and CPL file
    [digitalSystemBoard.kicad_pcb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]
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2021-05-11 Modify CPL and BOM file
    [MCU.sch, bomFile.xlsx, digitalSystemBoard.csv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]
2021-05-11 Fabrication output ver 2.0.1
    [digitalSystemBoard-B_Cu.gbl, digitalSystemBoard-B_Mask.gbs, digitalSystemBoard-B_Paste.gbp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]
2021-05-11 Update BOM and CPL for order
    [digitalSystemBoard.csv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]
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2021-06-01 Synchronize the name of all the device
    [DISPLAY.sch, MCU.sch, digitalSystemBoard.kicad_pcb]
2021-06-01 Fix footprint of LED and Button
    [MCU.sch, digitalSystemBoard.kicad_pcb]
2021-06-04 Add new footprint for led and button reset again
    [JLCSMT_DigitalSystemBoard_CPL1.xlsx, digitalSystemBoard-B_Cu.gbl, digitalSystemBoard-B_Mask.gbs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]
2021-06-10 Change part for R47K and C22pF
    [Header_and_Mounting.sch, digitalSystemBoard.csv, digitalSystemBoard.kicad_pcb]
2021-06-10 Fix error un similar between schematic and jlc
    [JLCSMT_DigitalSystemBoard_CPL1.xlsx, digitalSystemBoard-B_Cu.gbl, digitalSystemBoard-B_Mask.gbs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]
2021-06-16 Fix small bug
    [digitalSystemBoard.kicad_pcb]
2021-06-16 Add 3d symbol for power module!
    [Modul3d.step, digitalSystemBoard.kicad_pcb]
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2021-06-27 Fix U9 and Led0 display
    [digitalSystemBoard-B_Cu.gbl, digitalSystemBoard-B_Mask.gbs, digitalSystemBoard-B_Paste.gbp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]
2021-07-01 Change part of crystal
    [digitalSystemBoard.csv]
2021-11-13 Update MCU to ATmega64A
    [MCU.sch, digitalSystemBoard.kicad_pcb]
2021-11-14 Update file Gerber, CPL and BOM
    [digitalSystemBoard.kicad_pcb, dsBoard_BOM.csv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]
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2021-11-29 Debug the MISO, MOSI, TXD, RXD and INT2 route
    [MCU.sch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]
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2021-12-24 add plastic cover design
    [Part1.SLDDRW, Part1.sldprt, mica_ver2.0.DWG]
2021-12-27 Add LCD 3D model
    [WC1602A.step, digitalSystemBoard.kicad_pcb, dsBoard_BOM.csv]
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2022-01-05 Update USB and Fuse model
    [CUI_DEVICES_UJ2-BH-1-TH.step, Fuse.step, OS102011MS2QN1-3DModel-STEP-1.step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]
2022-01-05 Update Switch 3D model
    [OS102011MS2QN1-3DModel-STEP-1.step]
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2022-01-05 Update reset button model
    [FSM4JSMA_V2.step, digitalSystemBoard.kicad_pcb]
2022-01-05 Update PowerSwitch, Rheostat and Socket 3D model
    [PowerSwitch_V2.step, User-Library-DIP-16-_-socket-214_V2.step, User-Library-RK09K1130-20-1.step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]
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
